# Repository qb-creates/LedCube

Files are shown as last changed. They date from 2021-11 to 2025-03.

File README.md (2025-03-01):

# LED-Cube

LED Cube Display that projects custom animations using a 5x5x5 matrix of LEDs. The display utilizes an ATmega32 microcontroller utilizes two 16-channel LED drivers.

- Project Video (YouTube): https://www.youtube.com/watch?v=go_lMkQ88TE
- Display Multiplexing: https://en.wikipedia.org/wiki/Multiplexed_display

<div align="center">
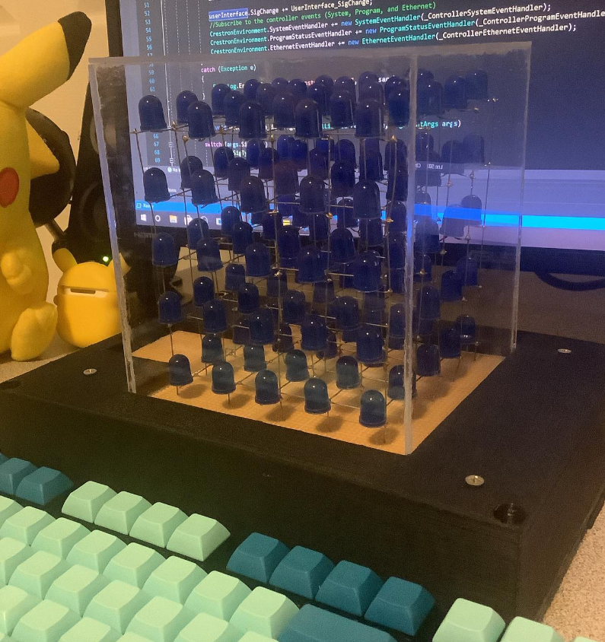
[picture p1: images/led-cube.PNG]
  
</div>

<h2> Table of Contents</h2>

1. [Software Used](#software)
2. [Cube Circuit](#cubecircuit)
    - [LED Driver](#leddriver)
    - [Parts List](#cubepartslist) 
3. [Power Consumption](#powerconsumption)
4. [Schematics](#schematics)
    - [Cube Schematic](#cubeschematic)

## 1. Software Used
- Microchip Studio: https://www.microchip.com/en-us/tools-resources/develop/microchip-studio
- AVRDUDE (Flash Uploader): https://github.com/avrdudes/avrdude
- KiCad (PCB Design): https://www.kicad.org
- AutoDesk Fusion 360 Personal (Case Design): https://www.autodesk.com/products/fusion-360/personal

## 2. Display Circuit 
This circuit projects custom animations by utilizing multiplexing and bit-angle modulation for LED dimming. Each layer of the cube consists of 25 LEDs, with their anodes soldered together and their cathodes connected to the CAT4016 constant current sink outputs. The LEDs are arranged into 25 vertical columns, each containing five LEDs stacked across the layers. The cathodes of LEDs within each column are connected together, allowing control of entire columns simultaneously. Five transistors act as switches to control each layer, allowing 5V to be applied to the corresponding anode mesh when the associated transistor is activated. Through multiplexing, all five layers can appear illuminated simultaneously. Communication with the LED drivers is achieved via the SPI protocol.

<div align="center">
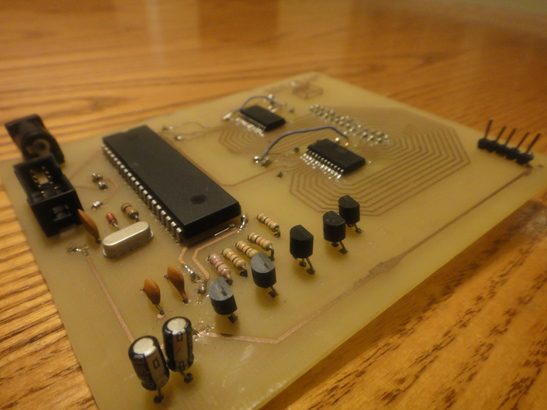
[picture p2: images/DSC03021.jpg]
  
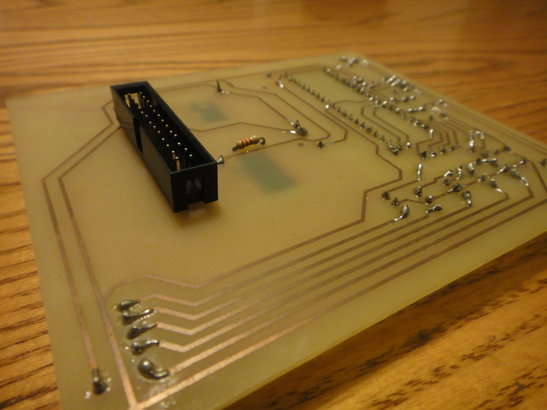
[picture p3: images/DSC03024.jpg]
  
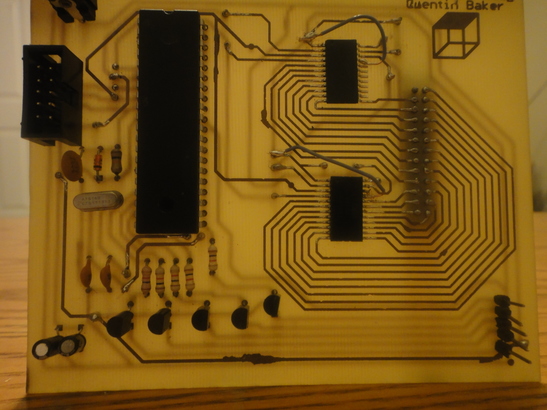
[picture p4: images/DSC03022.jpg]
  
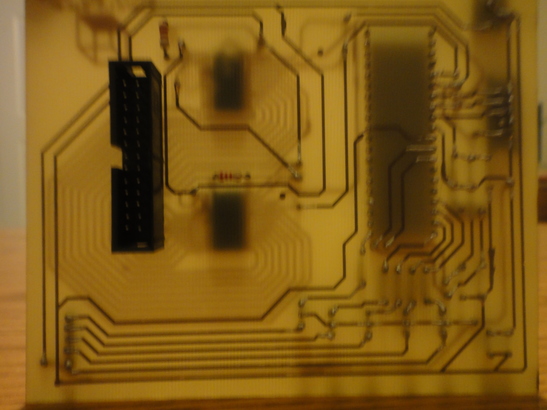
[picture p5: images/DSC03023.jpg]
  
</div>

### LED Drivers 
The LED Drivers are chained together. Each driver must receive two bytes of data to control their 16 output channels. Four bytes of data must be sent to the first driver in order to control all 32 output channels. The LEDs are mounted in order (starting from the top left corner of the 32 pin header connector) from 1 to 25. The table below shows which output channel each LED is connected to. 

|_**Cat4016 1 Outputs**_|LED Number|--|_**Cat4016 2 Outputs**_|LED Number|
|:--:|:--:|:--:|:--:|:--:|
|**Byte0**||--|**Byte2**||
|Out0|LED1|--|Out0|LED17|
|Out1|LED2|--|Out1|LED18|
|Out2|LED3|--|Out2|LED19|
|Out3|LED4|--|Out3|LED20|
|Out4|LED5|--|Out4|LED21|
|Out5|LED6|--|Out5|LED22|
|Out6|LED7|--|Out6|LED23|
|Out7|LED8|--|Out7|LED24|
|||--|||
|**Byte1**||--|**Byte3**||
|Out8|LED9|--|Out8|LED25|
|Out9|LED10|--|Out9|N/A|
|Out10|LED11|--|Out10|N/A|
|Out11|LED12|--|Out11|N/A|
|Out12|LED13|--|Out12|N/A|
|Out13|LED14|--|Out13|N/A|
|Out14|LED15|--|Out14|N/A|
|Out15|LED16|--|Out15|N/A|

Because the LED Drivers are daisy chained together, the data must be transmitted in the following order.
* Byte3 (MSB transmitted first) 
* Byte2 (LSB transmitted first) 
* Byte1 (MSB transmitted first) 
* Byte0 (LSB transmitted first) 
---

### Parts List 
|_**Part Number**_|_**Quantity**_|
|:-----|:---:|
|ATmega32-16PU| x1 |
|10 pin Header connector| x1 |
|32 pin header connector| x1 |
|Header Pins| x5 |
|(Cat4016 discontinued) STP16CPC05MTR LED Driver| x2 |
|10mm Blue Led| x125 |
|16Mhz Crystal| x1 |
|22pF Capacitor 0603 (1608 Metric)| x2 |
|100pF Capacitor 0603 (1608 Metric)| x3 |
|10K Resistor 0603 (1608 Metric)| x1 |
|2.2K Resistor 0603 (1608 Metric)| x2 |
|1K Resistor 0603 (1608 Metric)| x5 |
|1n4148 Diode| x1 |
|BC635 Transistor| x5 |

## 3. Power Consumption <a name="powerconsumption">
|_**Test Condition**_|_**Power Consumption**_|
|:--|:--:|
|Cube circuit with all LEDs powered on. LEDs are supplied with 27mA each.|700mA|

Since each layer of the cube is multiplexed, only 25 LEDs will be illuminated at any given time. As a result, the maximum power consumption for the LEDs is calculated as 27mA multiplied by 25, totaling 681mA. Additionally, the microcontroller itself consumes approximately 20mA. Therefore, the power supply must be capable of providing at least 700mA to ensure stable operation of all components. To allow for adequate headroom, a 1000mA (1A) power supply is recommended.

## 4. Schematics 
### Cube Schematic
<div>
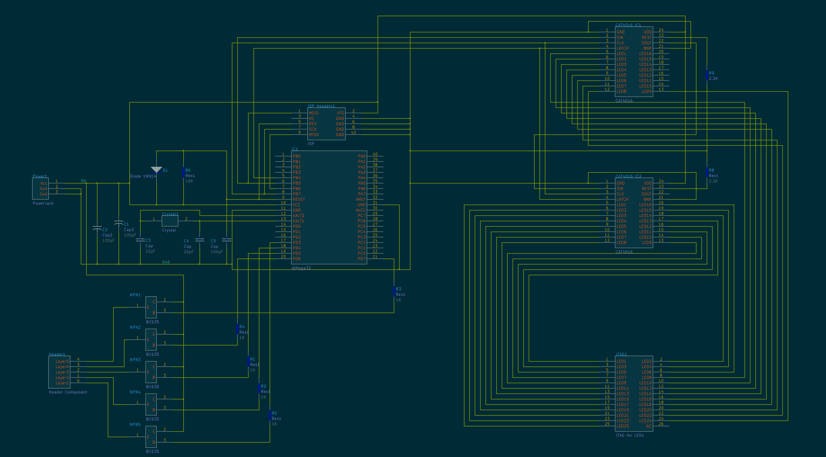
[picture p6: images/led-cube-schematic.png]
    
</div>

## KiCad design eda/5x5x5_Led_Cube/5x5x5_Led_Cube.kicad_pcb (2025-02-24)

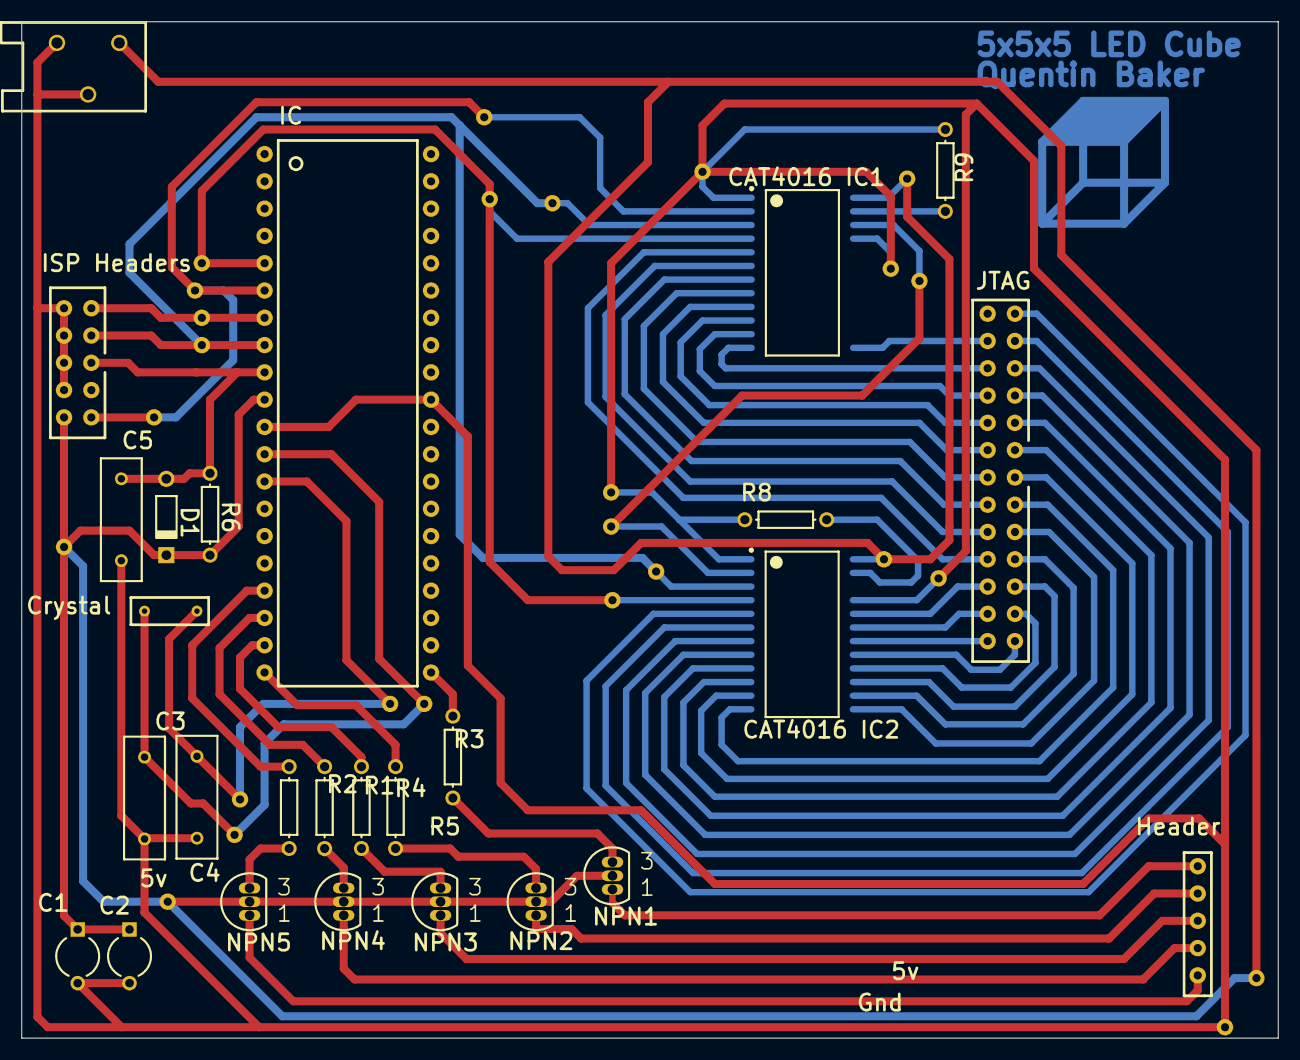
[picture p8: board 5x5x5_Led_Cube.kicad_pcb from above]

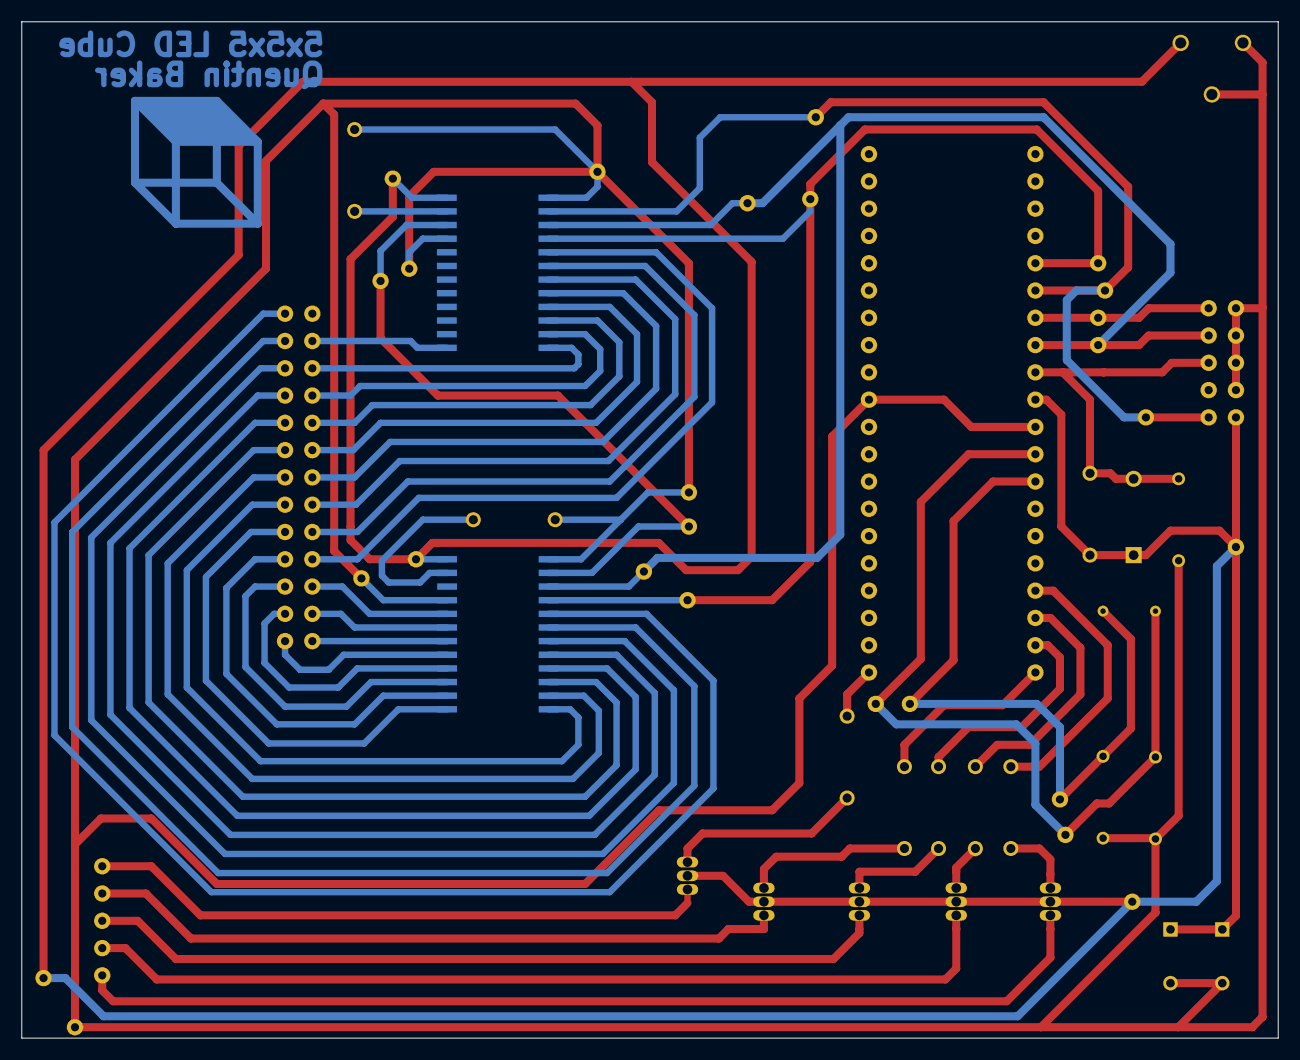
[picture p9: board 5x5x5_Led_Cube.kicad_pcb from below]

Board: 2 copper layers, 117.0 x 94.6 mm, 27 parts (27 on the bottom side), 11 nets.

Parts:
C1, C2: Cap2; CAPR5-4X5
C3, C4, C5: Cap; RAD-0.3
CAT4016 IC1, CAT4016 IC2: CAT4016; Cat4016
Crystal: Crystal
D1: Diode 1N914; DO-35
Header: Header Component; Layer_Headers
IC: Component_1; Atmega32DIP
ISP Headers: ISP; Shrouder Header
JTAG: Component_1; Shrouder Header 13
NPN1, NPN2, NPN3, NPN4, NPN5: BC635; BCY-W3
Power: Power_component; Barrel Jack
R1, R2, R3, R4, R5, R6, R8: Res1; AXIAL-0.3
R9: 2.2K; AXIAL-0.3

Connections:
5V: IC.10, ISP Headers.2, Power.1
/5V: C2.1, CAT4016 IC1.24 (VDD), CAT4016 IC2.24 (VDD), D1.2 (K), NPN1.2 (C), NPN2.2 (C), NPN3.2 (C), NPN4.2 (C), NPN5.2 (C), R6.1
/Gnd: C2.2, C3.1, C4.1, C5.1, CAT4016 IC1.1 (GND), CAT4016 IC1.21 (BNK), CAT4016 IC2.1 (GND), CAT4016 IC2.21 (BNK), R8.1, R9.1
GND: IC.11, IC.31, ISP Headers.4, ISP Headers.6, ISP Headers.8, ISP Headers.10, Power.2, Power.3
unnamed: D1.1 (A), R6.2
NetC3_2: Crystal.1, IC.12
NetC4_2: Crystal.2, IC.13
NetC5_2: IC.9, ISP Headers.5
NetCAT4016 IC1_2: IC.6, ISP Headers.1
NetCAT4016 IC1_3: IC.8, ISP Headers.7
NetIC_7: IC.7, ISP Headers.9

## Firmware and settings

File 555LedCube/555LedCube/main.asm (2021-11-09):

/*
 * _5x5x5_LED_Cube_Assembly.asm
 *
 *  Created: 10/10/2014 9:16:28 PM
 *   Author: Quentin
 */ 
.def first_animation = r18 ; define a temporary register
.def Alt_counter = r18
.def temp = r18; define a temp register
.def temp_2 = r19 ; define a temporary register
.def temp_3 = r20; define a temp register
.def temp_4 = r21 
.def Byte_1 = r22 ; define a temporary register
.def Byte_2 = r23 ; define a temporary register
.def Byte_3 = r24 ; define a temporary register
.def Byte_4 = r25 ; define a temporary register
.def Subtraction1 = r26 ; define a temporary register
.def Subtraction2 = r27 ; define a temporary register
.def Subtraction3 = r28 ; define a temporary register
.def Subtraction4 = r29 ; define a temporary register
.def counter = r30 ; define a temporary register
.def counter_2 = r31; define a temporary register


/*.def first_animation = r18 ; define a temporary register
.def Alt_counter = r18
.def temp_2 = r18; define a temp register
.def Byte_1 = r19 ; define a temporary register
.def temp_3 = r20; define a temp register
.def temp_4 = r21 
.def Byte_2 = r22 ; define a temporary register
.def Byte_3 = r23 ; define a temporary register
.def Byte_4 = r24 ; define a temporary register
.def temp = r25 ; define a temporary register
.def Subtraction1 = r26 ; define a temporary register
.def Subtraction2 = r27 ; define a temporary register
.def Subtraction3 = r28 ; define a temporary register
.def Subtraction4 = r29 ; define a temporary register
.def counter = r30 ; define a temporary register
.def counter_2 = r31; define a temporary register*/

//ldi first_animation, 0b10000000
 
;Initialize the microcontroller stack pointer
        LDI    R16, low(RAMEND)
        OUT    SPL, R16
        LDI    R16, high(RAMEND)
        OUT    SPH, R16

;Set up PORTD to be outputs
		ldi temp, 0xFF
		out DDRD, temp
		ldi temp, 0x00
		out PORTD, temp
		
;Sets up peripherals
		Call SPI_MasterInit																		;
;Main Program Loop
Main:

		Call Light_Rail 
		Call Light_Rail2
		Call Clear
		Call Twister
		Call Clear
		Call Expand_1 Call Expand_2 Call Expand_3 Call Expand_4 
		Call Expand_1 Call Expand_2 Call Expand_3 Call Expand_4 
		Call Rain_Fall
		Call Wave
		Call Clear
	ldi Subtraction4, 0b00000000
		Call Explode 
	ldi Subtraction4, 0b11111111
		Call Explode 
		Call Clear
		Call Snake 
		Call Clear
		Call Cage
		Call Clear
		Call Spiral
		Call Clear
		Call Piece_Together 
		Call Lightning
		rjmp Main

																																			
											
		.include "F:\Bitbucket\Atmel Studio\555-led-cube\555LedCube\555LedCube\Explode_Animation.asm"
		.include "F:\Bitbucket\Atmel Studio\555-led-cube\555LedCube\555LedCube\Light_Rail_Animation.asm"
		.include "F:\Bitbucket\Atmel Studio\555-led-cube\555LedCube\555LedCube\Rain_Fall_Animation.asm"
		.include "F:\Bitbucket\Atmel Studio\555-led-cube\555LedCube\555LedCube\Twister_Animation.asm"	
		.include "F:\Bitbucket\Atmel Studio\555-led-cube\555LedCube\555LedCube\Wave_Animation.asm"	
		.include "F:\Bitbucket\Atmel Studio\555-led-cube\555LedCube\555LedCube\Expand_Animation.asm"
		.include "F:\Bitbucket\Atmel Studio\555-led-cube\555LedCube\555LedCube\Lightning_Animation.asm"
		.include "F:\Bitbucket\Atmel Studio\555-led-cube\555LedCube\555LedCube\Cage_Animation.asm"	
		.include "F:\Bitbucket\Atmel Studio\555-led-cube\555LedCube\555LedCube\Spiral_Animation.asm"	
		.include "F:\Bitbucket\Atmel Studio\555-led-cube\555LedCube\555LedCube\Snake_Animation.asm"
		.include "F:\Bitbucket\Atmel Studio\555-led-cube\555LedCube\555LedCube\Piece_Together_Animation.asm"
		.include "F:\Bitbucket\Atmel Studio\555-led-cube\555LedCube\555LedCube\Brightness.asm"
		.include "F:\Bitbucket\Atmel Studio\555-led-cube\555LedCube\555LedCube\Clear.asm"
		.include "F:\Bitbucket\Atmel Studio\555-led-cube\555LedCube\555LedCube\SPI_Initialization.asm"
		.include "F:\Bitbucket\Atmel Studio\555-led-cube\555LedCube\555LedCube\Delay_Function.asm"																													;

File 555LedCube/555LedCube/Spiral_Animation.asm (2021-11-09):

/*
 * Spiral_Animation.asm
 *
 *  Created: 4/10/2017 11:29:22 AM
 *   Author: qbake_0
 */ 
 /////////////////////////////////////////////////////////////////////////////////////////////////////////////////////////////////////
Spiral:																														;
	ldi Xh, 0x00																											;
	ldi Xl, 0xAA																											;
	ldi temp, 0x00 ST X+, temp	ldi temp, 0x00 ST X+, temp	ldi temp, 0x00 ST X+, temp	ldi temp, 0x00 ST X+, temp			;
	ldi temp, 0x00 ST X+, temp	ldi temp, 0x00 ST X+, temp	ldi temp, 0x00 ST X+, temp	ldi temp, 0x00 ST X+, temp			;
	ldi temp, 0x00 ST X+, temp	ldi temp, 0x00 ST X+, temp	ldi temp, 0x00 ST X+, temp	ldi temp, 0x00 ST X+, temp			;
	ldi temp, 0x00 ST X+, temp	ldi temp, 0x00 ST X+, temp	ldi temp, 0x00 ST X+, temp	ldi temp, 0x00 ST X+, temp			;
	ldi temp, 0x00 ST X+, temp	ldi temp, 0x00 ST X+, temp	ldi temp, 0x00 ST X+, temp	ldi temp, 0x00 ST X+, temp			;
	ldi temp, 0x00 ST X+, temp	ldi temp, 0x00 ST X+, temp	ldi temp, 0x00 ST X+, temp	ldi temp, 0x00 ST X+, temp			;
																															;
	ldi Subtraction4, 8																										;
Spiral_loop:																												;
																															;
	ldi Xh, 0x00																											;
	ldi Xl, 0xAE																											;
	ldi temp, 0x00 ST X+, temp	ldi temp, 0x00 ST X+, temp	ldi temp, 0x04 ST X+, temp	ldi temp, 0x00 ST X+, temp			;
	Call Spiral_function																									;
																															;
	ldi Xh, 0x00																											;
	ldi Xl, 0xAE																											;
	ldi temp, 0x00 ST X+, temp	ldi temp, 0x00 ST X+, temp	ldi temp, 0x02 ST X+, temp	ldi temp, 0x00 ST X+, temp			;
	Call Spiral_function																									;
																															;
	ldi Xh, 0x00																											;
	ldi Xl, 0xAE																											;
	ldi temp, 0x00 ST X+, temp	ldi temp, 0x00 ST X+, temp	ldi temp, 0x01 ST X+, temp	ldi temp, 0x00 ST X+, temp			;
	Call Spiral_function																									;
																															;
	ldi Xh, 0x00																											;
	ldi Xl, 0xAE																											;
	ldi temp, 0x00 ST X+, temp	ldi temp, 0x08 ST X+, temp	ldi temp, 0x00 ST X+, temp	ldi temp, 0x00 ST X+, temp			;
	Call Spiral_function																									;
																															;
	ldi Xh, 0x00																											;
	ldi Xl, 0xAE																											;
	ldi temp, 0x40 ST X+, temp	ldi temp, 0x00 ST X+, temp	ldi temp, 0x00 ST X+, temp	ldi temp, 0x00 ST X+, temp			;
	Call Spiral_function																									;
																															;
	ldi Xh, 0x00																											;
	ldi Xl, 0xAE																											;
	ldi temp, 0x80 ST X+, temp	ldi temp, 0x00 ST X+, temp	ldi temp, 0x00 ST X+, temp	ldi temp, 0x00 ST X+, temp			;
	Call Spiral_function																									;
																															;
	ldi Xh, 0x00																											;
	ldi Xl, 0xAE																											;
	ldi temp, 0x00 ST X+, temp	ldi temp, 0x01 ST X+, temp	ldi temp, 0x00 ST X+, temp	ldi temp, 0x00 ST X+, temp			;
	Call Spiral_function																									;
																															;
	ldi Xh, 0x00																											;
	ldi Xl, 0xAE																											;
	ldi temp, 0x00 ST X+, temp	ldi temp, 0x20 ST X+, temp	ldi temp, 0x00 ST X+, temp	ldi temp, 0x00 ST X+, temp			;
	Call Spiral_function																									;
																															;
	ldi Xh, 0x00																											;
	ldi Xl, 0xAE																											;
	ldi temp, 0x00 ST X+, temp	ldi temp, 0x00 ST X+, temp	ldi temp, 0x04 ST X+, temp	ldi temp, 0x00 ST X+, temp			;
	Call Spiral_function																									;
																															;
	ldi Xh, 0x00																											;
	ldi Xl, 0xAE																											;
	ldi temp, 0x00 ST X+, temp	ldi temp, 0x00 ST X+, temp	ldi temp, 0x02 ST X+, temp	ldi temp, 0x00 ST X+, temp			;
	Call Spiral_function																									;
																															;
	ldi Xh, 0x00																											;
	ldi Xl, 0xAE																											;
	ldi temp, 0x00 ST X+, temp	ldi temp, 0x00 ST X+, temp	ldi temp, 0x01 ST X+, temp	ldi temp, 0x00 ST X+, temp			;
	Call Spiral_function																									;
																															;
	ldi Xh, 0x00																											;
	ldi Xl, 0xAE																											;
	ldi temp, 0x00 ST X+, temp	ldi temp, 0x08 ST X+, temp	ldi temp, 0x00 ST X+, temp	ldi temp, 0x00 ST X+, temp			;
	Call Spiral_function																									;
																															;
	ldi Xh, 0x00																											;
	ldi Xl, 0xAE																											;
	ldi temp, 0x40 ST X+, temp	ldi temp, 0x00 ST X+, temp	ldi temp, 0x00 ST X+, temp	ldi temp, 0x00 ST X+, temp			;
	Call Spiral_function																									;
																															;
	ldi Xh, 0x00																											;
	ldi Xl, 0xAE																											;
	ldi temp, 0x80 ST X+, temp	ldi temp, 0x00 ST X+, temp	ldi temp, 0x00 ST X+, temp	ldi temp, 0x00 ST X+, temp			;
	Call Spiral_function																									;
																															;
	ldi Xh, 0x00																											;
	ldi Xl, 0xAE																											;
	ldi temp, 0x00 ST X+, temp	ldi temp, 0x01 ST X+, temp	ldi temp, 0x00 ST X+, temp	ldi temp, 0x00 ST X+, temp			;
	Call Spiral_function																									;
																															;
	ldi Xh, 0x00																											;
	ldi Xl, 0xAE																											;
	ldi temp, 0x00 ST X+, temp	ldi temp, 0x20 ST X+, temp	ldi temp, 0x00 ST X+, temp	ldi temp, 0x00 ST X+, temp			;
	Call Spiral_function																									;
																															;
	ldi Xh, 0x00																											;
	ldi Xl, 0xAE																											;
	ldi temp, 0x00 ST X+, temp	ldi temp, 0x00 ST X+, temp	ldi temp, 0x04 ST X+, temp	ldi temp, 0x00 ST X+, temp			;
	Call Spiral_function																									;
																															;
	ldi Xh, 0x00																											;
	ldi Xl, 0xAE																											;
	ldi temp, 0x00 ST X+, temp	ldi temp, 0x00 ST X+, temp	ldi temp, 0x02 ST X+, temp	ldi temp, 0x00 ST X+, temp			;
	Call Spiral_function																									;
																															;
	ldi Xh, 0x00																											;
	ldi Xl, 0xAE																											;
	ldi temp, 0x00 ST X+, temp	ldi temp, 0x00 ST X+, temp	ldi temp, 0x01 ST X+, temp	ldi temp, 0x00 ST X+, temp			;
	Call Spiral_function																									;
																															;
	ldi Xh, 0x00																											;
	ldi Xl, 0xAE																											;
	ldi temp, 0x00 ST X+, temp	ldi temp, 0x08 ST X+, temp	ldi temp, 0x00 ST X+, temp	ldi temp, 0x00 ST X+, temp			;
	Call Spiral_function																									;
																															;
	ldi Xh, 0x00																											;
	ldi Xl, 0xAE																											;
	ldi temp, 0x40 ST X+, temp	ldi temp, 0x00 ST X+, temp	ldi temp, 0x00 ST X+, temp	ldi temp, 0x00 ST X+, temp			;
	Call Spiral_function																									;
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

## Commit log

2025-02-24 Add files via upload
    Adding new led cube image
2025-02-24 Update README.md
    Updated the read me to include the new led cub image. Updated the LED Drivers section.
2025-02-24 Update README.md
    Added schematic and power consumption sections
2025-02-24 - Updated git ignore to include kicad projects
2025-02-24 - removed old schematic pdf and added new led cube schematic - Added led cube kicad solution - Added new schematic to the readme
    [5x5x5_Led_Cube.kicad_pcb, 5x5x5_Led_Cube.kicad_sch]
2025-02-24 - Updated power consumption section of the read me.
2025-02-24 - Updated the Display Circuit description
2025-03-01 Update README.md
    Updated led cube image on readme
